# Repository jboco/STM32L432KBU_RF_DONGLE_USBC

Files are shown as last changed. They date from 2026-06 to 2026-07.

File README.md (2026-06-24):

# STM32L432KBU 2.4GHz RF Dongle USB Type-C

An open-source, ultra-compact RF development dongle featuring an **STM32L432KBU** microcontroller paired with a **Nordic Semiconductor nRF24L01** 2.4GHz wireless transceiver and a USB-C port. 

> ⚠️ **Status: Work in Progress / Untested.** This design is currently undergoing community review and has not yet been physically fabricated or validated on a test bench. Use at your own discretion.

---

## Design Previews

### 3D Render View
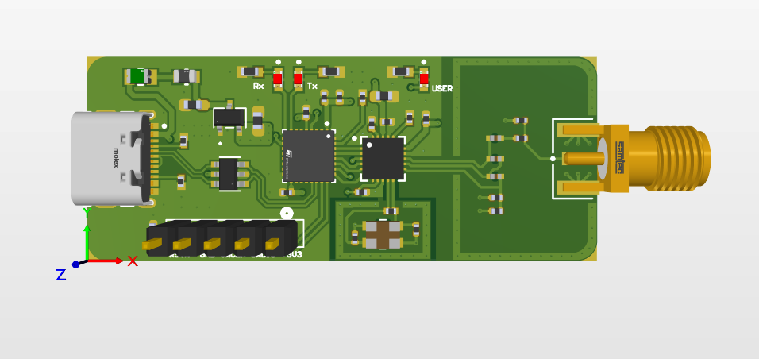
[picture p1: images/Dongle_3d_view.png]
3D Rendering of the RF Dongle


### PCB Layout View
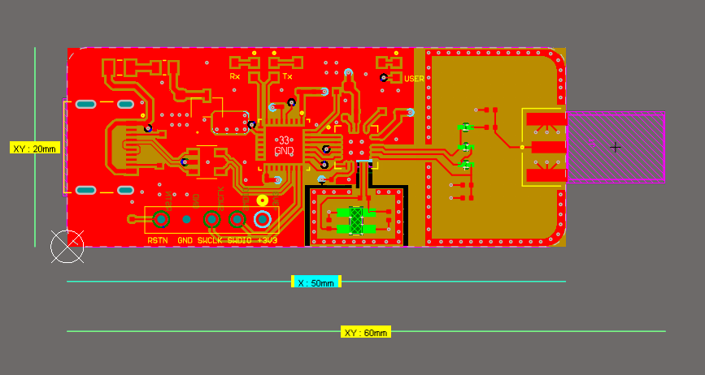
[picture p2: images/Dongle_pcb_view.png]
2D PCB Trace Layout and Routing


---

## Technical Specifications

### Hardware Architecture
* **MCU:** STM32L432KBU6 (ARM Cortex-M4 @ 80MHz, 256KB Flash, 64KB SRAM)
* **RF Transceiver:** nRF24L01+ (2.4GHz ISM Band, GFSK modulation, up to 2Mbps data rate)
* **Interface:** Native USB 2.0 via a physical **USB Type-C Connector**
* **Visual Diagnostics:** * `PA2` linked to Dedicated Hardware TX Status LED
  * `PA3` linked to Dedicated Hardware RX Status LED
  * `PA4` linked to General Purpose User LED

### Mechanical Dimensions
* **Width:** 20 mm
* **Length:** 60 mm
* **Form Factor:** Slim USB-stick profile with an integrated PCB trace or edge-mounted antenna footprint.

---

## PCB Manufacturing & Layer Stackup

This board is designed strictly around the **JLCPCB 4-Layer Controlled Impedance Stackup (JLC04161H-3313)** using a standard **1.6mm total board thickness**. This specific pre-preg and core arrangement is critical for maintaining correct 50Ω trace impedance matching for the 2.4GHz RF front-end.

### Layer Structure

| Layer | Type | Material | Thickness | Constant ($\epsilon_r$) |
| :--- | :--- | :--- | :--- | :--- |
| **Top Layer** | Signal / Copper | Copper (1 oz) | 0.035 mm | — |
| *Prepreg* | Dielectric | **7628\*1** | 0.2104 mm | 4.4 |
| **Internal Layer 2** | Plane / GND | Copper (0.5 oz)| 0.0175 mm | — |
| *Core* | Dielectric | **Core** | 1.065 mm | 4.5 |
| **Internal Layer 3** | Signal / Power | Copper (0.5 oz)| 0.0175 mm | — |
| *Prepreg* | Dielectric | **7628\*1** | 0.2104 mm | 4.4 |
| **Bottom Layer** | Signal / Copper | Copper (1 oz) | 0.035 mm | — |

---

## Repository Structure & Usage

This repository contains **source design files only**. To ensure workspace flexibility, components are cleanly bound directly inside the project archive.

* **`/Hardware`**
  * `*.PrjPcb` - Altium Project Binder
  * `*.SchDoc` - Schematic Sheets
  * `*.PcbDoc` - PCB Layout Geometry
  * `*.SchLib` & `*.PcbLib` - Complete component library assets including 3D STEP models.

### How to Review
1. Clone this repository locally.
2. Open the `.PrjPcb` file inside Altium Designer.
3. Reviewers are encouraged to verify trace geometry tolerances, decoupling capacitor loops, and RF ground pour integrity before submitting feedback via GitHub Issues.

### Keywords & Search Tags
STM32L432 Reference Design, nRF24L01 Schematic, USB-C Dongle Hardware, 4-Layer Controlled Impedance PCB, Altium RF Layout, JLC04161H-3313, 2.4GHz Antenna Breakout.

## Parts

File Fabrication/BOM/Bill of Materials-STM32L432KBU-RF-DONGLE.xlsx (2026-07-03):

Comment | Description | Designator | Footprint | LibRef | Quantity | LCSC Part # | Manufacturer_Part_Number | Manufacturer_Name
100nF | Chip Capacitor, 100 nF | C1, C10, C11, C12 | CAPC1005X55N | CAP-0402-100NF | 4 | C1525
1.5pF | Chip Capacitor, 1.5 pF | C2 | CAPC1005X55N | CAP-0402-1P5F | 1 | C76901
12pF | Chip Capacitor, 12 pF | C3, C5 | CAPC1005X55N | CAP-0402-12PF | 2 | C2235030
1.0pF | Chip Capacitor, 1.0 pF | C4 | CAPC1005X55N | CAP-0402-1PF | 1 | C76898
33nF | Chip Capacitor, 33 nF | C6 | CAPC1005X55N | CAP-0402-33NF | 1 | C126535
2.2nF | Chip Capacitor, 2.2 nF | C7 | CAPC1005X55N | CAP-0402-2N2F | 1 | C2987940
4.7pF | Chip Capacitor, 4.7 pF | C8 | CAPC1005X55N | CAP-0402-4P7F | 1 | C161327
1uF | Chip Capacitor, 1 uF | C9 | CAPC1005X55N | CAP-0402-1UF | 1 | C52923
10uF | Chip Capacitor, 10 uF | C13, C17, C18 | CAPC1608X90 | CAP-0603-10UF | 3 | C22418930
10nF | Chip Capacitor, 10 nF | C14, C15, C16 | CAPC1005X55N | CAP-0402-10NF | 3 | C15195
USBLC6-2SC6 | ESD Protection for USB 2.0 High Speed | CR1 | SOT23-6L_STM | USBLC6-2SC6 | 1 | C5261088 | USBLC6-2SC6 | STMicroelectronics
SML-LX0603IW-TR | LED RED DIFFUSED SMD | D1, D2, D3 | FP-SML-LX0603IW-TR-MFG | SML-LX0603IW-TR | 3 | C5354817
0805L010YR | 0805L010YR PTC Resettable Fuse 0.1A(hold) 0.3A(trip) 15VDC 100A 0.5W 1.5s 1Ohm SMD Solder Pad 0805 T/R | F1 | FP-0805L010-MFG | 0805L010YR | 1 | C207020
MPZ2012S101AT000 | FERRITE BEAD 100 OHM 0805 1LN | FB1 | FP-MPZ2012-IPC_A | MPZ2012S101AT000 | 1 | C15957
SMA-J-P-H-ST-EM1 | CONN SMA JACK STR 50OHM EDGE MNT | J1 | FP-SMA-J-P-H-ST-EM1-MFG | SMA-J-P-H-ST-EM1 | 1 | C5199907
TSW-105-07-G-S | Conn Unshrouded Header HDR 5 POS 2.54mm Solder ST Top Entry Thru-Hole Bag | J2 | CON5_1X5_TU_TSW | TSW-105-07-G-S | 1 | C5993812 | TSW-105-07-G-S | Samtec Inc
217179-0001 | CONN RCP USB2.0 TYP C 24P SMD RA | J3 | FP-2171790001-MFG | 217179-0001 | 1 | C3197684
3.9nH | Inductor SMD | L1 | IND_LQG15HS3N3S02D_MUR | IND SMD 3.9nH | 1 | C77109
8.2nH | Inductor SMD | L2 | IND_LQG15HS3N3S02D_MUR | IND SMD 8.2nH | 1 | C98003
2.7nH | Inductor SMD | L3 | IND_LQG15HS3N3S02D_MUR | IND SMD 2.7nH | 1 | C77108
10K | RES 10kΩ ±1% 62.5mW 0402 | R1 | RESC1005X37N | RES-0402-10K | 1 | C60490
1M | RES 1MΩ ±1% 62.5mW 0402 | R2 | RESC1005X37N | RES-0402-1M | 1 | C2906900
22K | RES 22kΩ ±1% 62.5mW 0402 | R3 | RESC1005X37N | RES-0402-22K | 1 | C82868
1K | RES 1KΩ ±1% 62.5mW 0603 | R4, R5, R8 | RESC1608X55N | RES-0603-1K | 3 | C2907002
5K1 | RES 5K1Ω ±1% 62.5mW 0402 | R6, R7 | RESC1005X37N | RES-0402-5K1 | 2 | C723526
NRF24L01P-T | Single Chip Transceiver, 2.4 GHz, 60 mW, 1.9 to 3.6 V, -40 to 85 degC, 20-Pin QFN, RoHS, Tray | U1 | NRSC-QFN-20_L | NRF24L01P-T | 1 | C1526140
STM32L432KBU6 | IC MCU 32BIT 128KB FLASH 32QFPN | U2 | FP-UFQFPN32-A0B8-MFG | STM32L432KBU6 | 1 | C94784
X322516MLB4SI 16MHz | CRYSTAL 16MHz 9pF SMD | U3 | CHIP_X32B4SI_SYX | X322516MLB4SI | 1 | C13738 | X322516MLB4SI | Shenzhen Yang Xing Technology
XC6206P332MR-G | Low ESR Cap. Compatible Positive Voltage Regulators | U4 | SOT-23_TOR | XC6206P332MR-G | 1 | C5446 | XC6206P332MR-G | Torex Semiconductor

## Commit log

2026-06-24 Initial commit: Add hardware design files and project structure
    [PCB1.PcbDoc, PcbLib1.PcbLib, STM32L432KBU-RF-DONGLE.PrjPcb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]
2026-06-24 Repoured polygons and added JLC04161H stackup specifications and layout images
    [PCB1.PcbDoc]
2026-06-26 Added labels to schematic sheet
    [Sheet1.SchDoc]
2026-07-03 Added LCSC part numbers and production files (gerbers, NC drills).
    [Bill of Materials-STM32L432KBU-RF-DONGLE.xlsx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]
